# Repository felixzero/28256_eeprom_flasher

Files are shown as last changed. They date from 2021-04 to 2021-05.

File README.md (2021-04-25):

# 28256_eeprom_flasher
Hardware and software for an EEPROM flasher for 28256 EEPROMs.

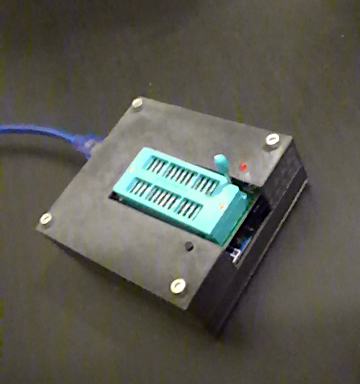
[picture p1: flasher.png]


## How does it work?
- The electronics CAD files are in the `electronics`. You will need Kicad to open them.
- The 3d printed plastic enclosure CAD files are in the `mechanical` folder. You will need FreeCAD.
- The Arduino sketch is in the `firmware` folder.
- The Python script (to communicate with the flasher) is in the `software` folder.

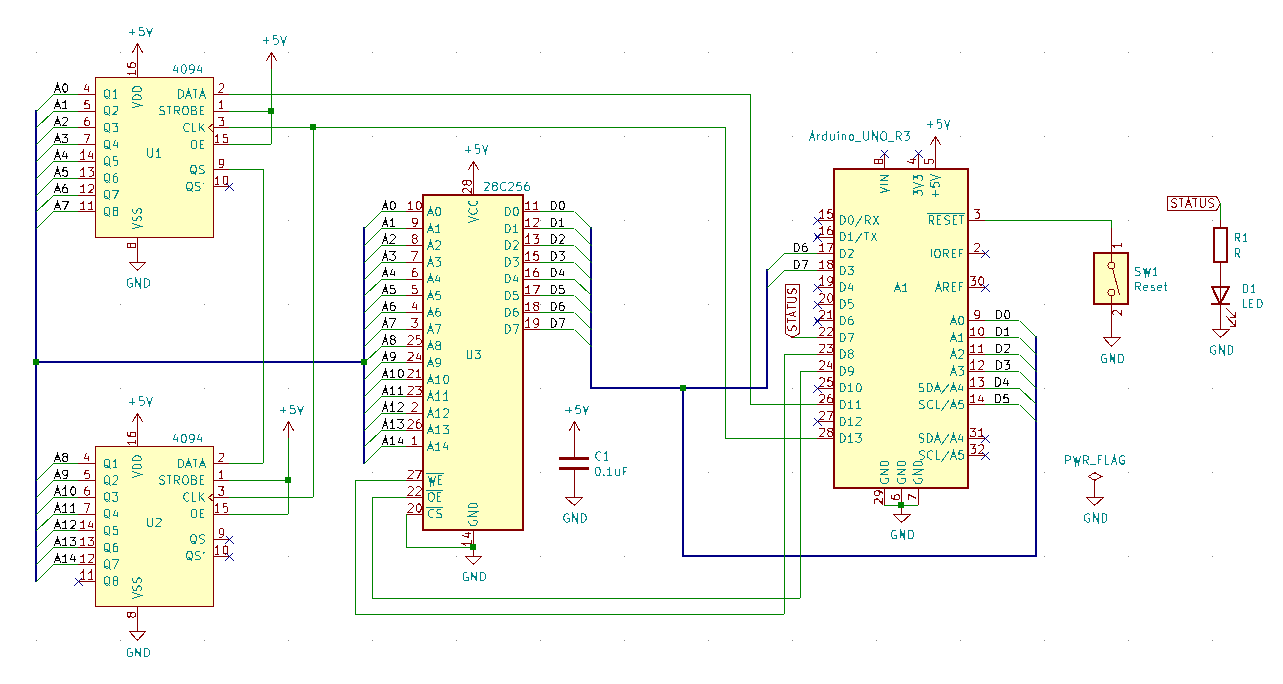
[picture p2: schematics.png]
Electrical schematics


## I just want it
Then you can simply download [the production files](production-files.zip):
- Send the `gerber.zip` file to a PCB manufacturer
- Use a 3d printer to print the two `.obj` files
- Checkout the Git repository to download the software

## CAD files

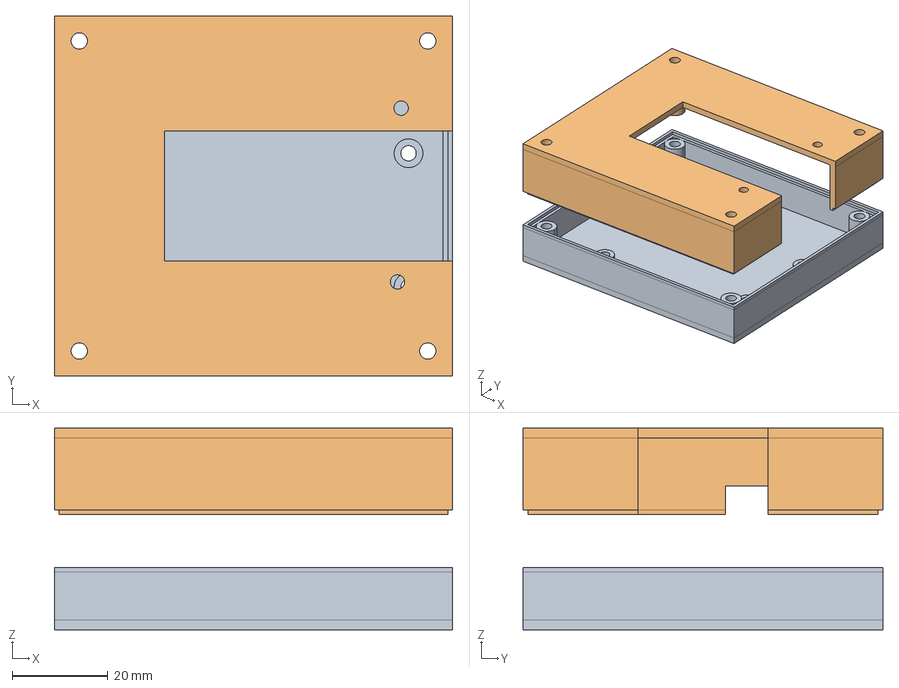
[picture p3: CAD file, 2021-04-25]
mechanical/enclosure.FCStd
83.0 x 75.0 x 42.0 mm
Fond
Dessus

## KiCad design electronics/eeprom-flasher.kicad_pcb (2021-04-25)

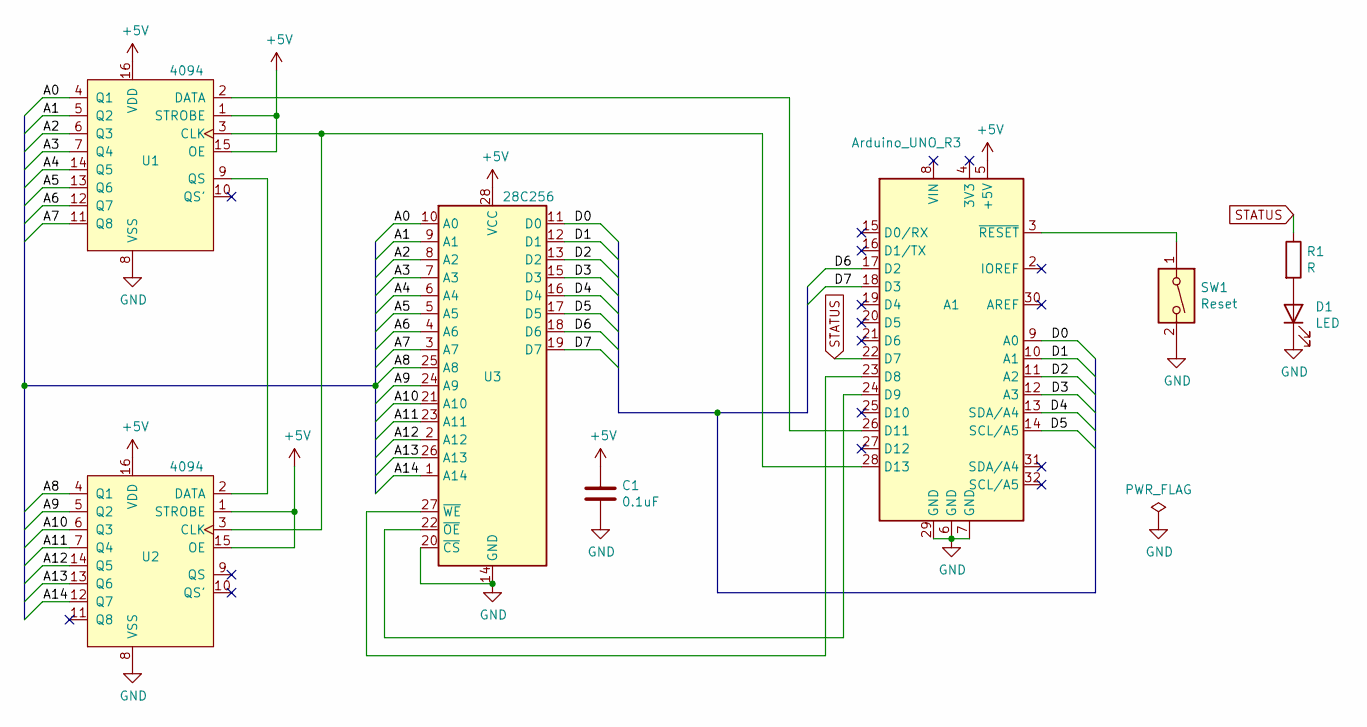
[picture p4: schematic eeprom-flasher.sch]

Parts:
A1: Arduino_UNO_R3
C1: 0.1uF; C_Rect_L7.2mm_W3.0mm_P5.00mm_FKS2_FKP2_MKS2_MKP2
D1: LED; LED_D3.0mm_FlatTop
R1: R; R_Axial_DIN0207_L6.3mm_D2.5mm_P2.54mm_Vertical
SW1: Reset; SW_PUSH_6mm
U1, U2: 4094; DIP-16_W7.62mm_LongPads
U3: 28C256; DIP_Socket-28_W11.9_W12.7_W15.24_W17.78_W18.5_3M_228-1277-0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

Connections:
+5V: A1.5 (+5V), C1.1, U1.1 (STROBE), U1.15 (OE), U1.16 (VDD), U2.1 (STROBE), U2.15 (OE), U2.16 (VDD), U3.28 (VCC)
/A0: U1.4 (Q1), U3.10 (A0)
/A1: U1.5 (Q2), U3.9 (A1)
/A2: U1.6 (Q3), U3.8 (A2)
/A3: U1.7 (Q4), U3.7 (A3)
/A4: U1.14 (Q5), U3.6 (A4)
/A5: U1.13 (Q6), U3.5 (A5)
/A6: U1.12 (Q7), U3.4 (A6)
/A7: U1.11 (Q8), U3.3 (A7)
/A8: U2.4 (Q1), U3.25 (A8)
/A9: U2.5 (Q2), U3.24 (A9)
/A10: U2.6 (Q3), U3.21 (A10)
/A11: U2.7 (Q4), U3.23 (A11)
/A12: U2.14 (Q5), U3.2 (A12)
/A13: U2.13 (Q6), U3.26 (A13)
/A14: U2.12 (Q7), U3.1 (A14)
/D0: A1.9 (A0), U3.11 (D0)
/D1: A1.10 (A1), U3.12 (D1)
/D2: A1.11 (A2), U3.13 (D2)
/D3: A1.12 (A3), U3.15 (D3)
/D4: A1.13 (SDA/A4), U3.16 (D4)
/D5: A1.14 (SCL/A5), U3.17 (D5)
/D6: A1.17 (D2), U3.18 (D6)
/D7: A1.18 (D3), U3.19 (D7)
GND: A1.6 (GND), A1.7 (GND), A1.29 (GND), C1.2, D1.1 (K), SW1.2, U1.8 (VSS), U2.8 (VSS), U3.14 (GND), U3.20 (~CS)
unnamed: A1.3 (~RESET), SW1.1
unnamed: A1.23 (D8), U3.27 (~WE)
unnamed: A1.24 (D9), U3.22 (~OE)
unnamed: A1.26 (D11), U1.2 (DATA)
unnamed: A1.28 (D13), U1.3 (CLK), U2.3 (CLK)
unnamed: D1.2 (A), R1.2
unnamed: U1.9 (QS), U2.2 (DATA)
STATUS: A1.22 (D7), R1.1

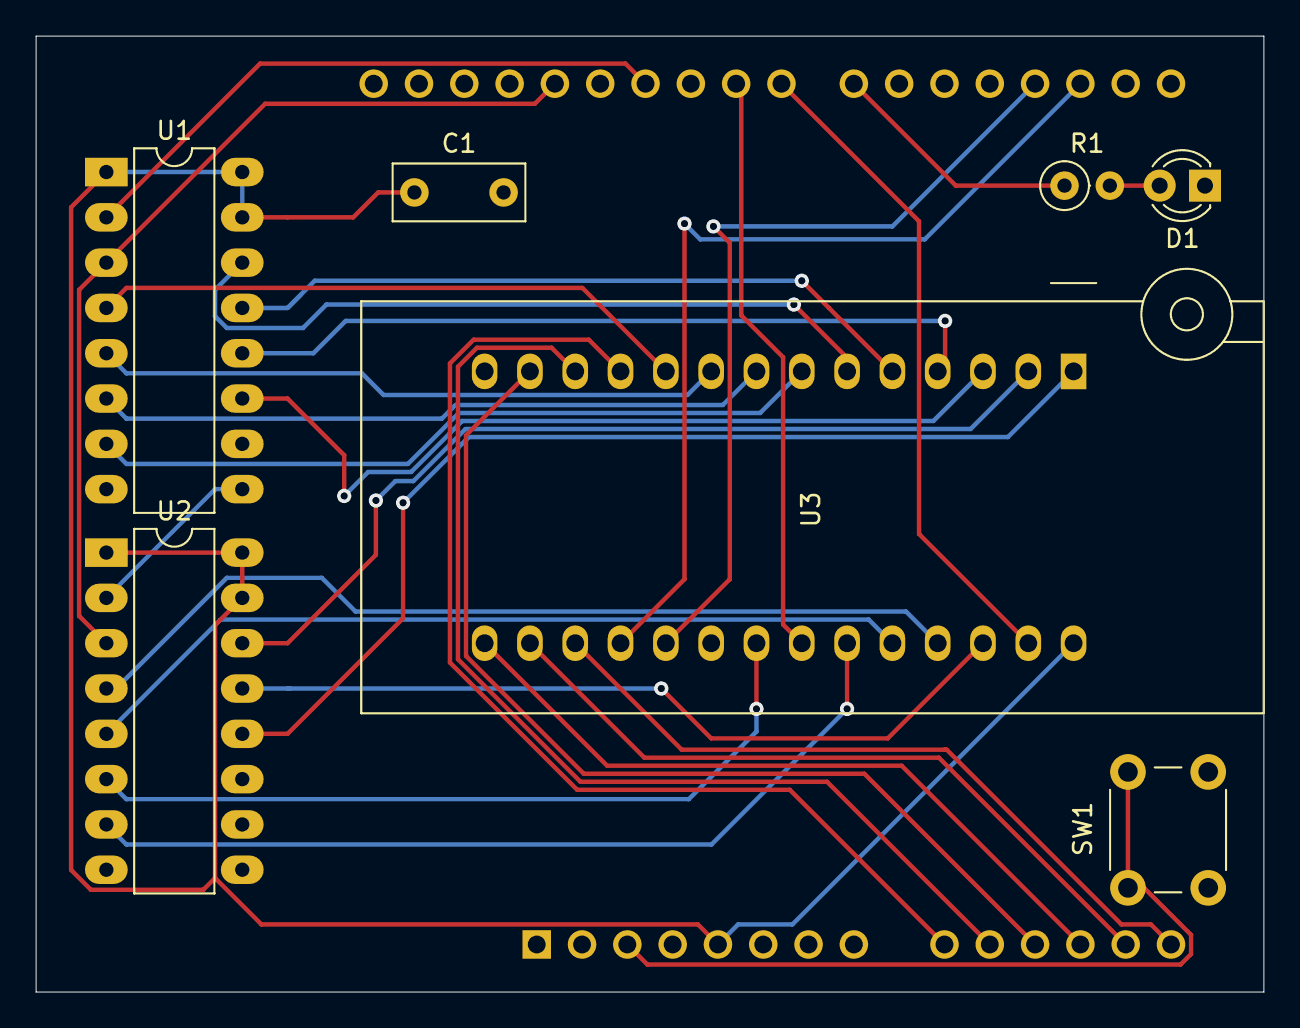
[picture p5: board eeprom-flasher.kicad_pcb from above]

Board: 2 copper layers, 68.8 x 53.6 mm, 8 parts (1 on the bottom side), 33 nets.

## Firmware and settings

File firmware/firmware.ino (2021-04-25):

#define SERIAL_BAUD_RATE 115200

#define PAGE_SIZE 64

#define READ_PAGE_CMD 'r'
#define WRITE_PAGE_CMD 'w'

#define PROCESSED '0'
#define ERROR_INVALID_COMMAND '1'
#define ERROR_BUFFER_TIMEOUT '2'
#define ERROR_ADDR_NOT_AT_BEGINNING_OF_PAGE '3'

#include "eeprom.h"

void setup() {
  Serial.begin(SERIAL_BAUD_RATE);
  Flasher.begin();
}

void loop() {
  if (!Serial.available()) {
    return;
  }

  uint8_t command_byte;
  Serial.readBytes(&command_byte, 1);

  switch(command_byte) {
  case READ_PAGE_CMD:
    handle_read();
    break;

  case WRITE_PAGE_CMD:
    handle_write();
    break;

  default:
    handle_error(ERROR_INVALID_COMMAND);
  }
}

void handle_read() {
  static uint8_t read_buffer[2];
  static uint8_t output_buffer[PAGE_SIZE];
  
  if (Serial.readBytes(read_buffer, 2) != 2) {
    handle_error(ERROR_BUFFER_TIMEOUT);
    return;
  }

  uint16_t eeprom_addr = read_buffer[0] + read_buffer[1] * 256;
  if (eeprom_addr % PAGE_SIZE != 0) {
    handle_error(ERROR_ADDR_NOT_AT_BEGINNING_OF_PAGE);
    return;
  }

  Flasher.read_page(eeprom_addr, output_buffer);
  Serial.write(PROCESSED);
  Serial.write(output_buffer, PAGE_SIZE);
}

void handle_write() {
  static uint8_t read_buffer[PAGE_SIZE + 2];
  
  if (Serial.readBytes(read_buffer, PAGE_SIZE + 2) != (PAGE_SIZE + 2)) {
    handle_error(ERROR_BUFFER_TIMEOUT);
    return;
  }

  uint16_t eeprom_addr = read_buffer[0] + read_buffer[1] * 256;
  if (eeprom_addr % PAGE_SIZE != 0) {
    handle_error(ERROR_ADDR_NOT_AT_BEGINNING_OF_PAGE);
    return;
  }

  Flasher.write_page(eeprom_addr, read_buffer + 2);
  Serial.write(PROCESSED);
}

void handle_error(char error_code) {
  Serial.write(error_code);
}

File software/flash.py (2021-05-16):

#!/usr/bin/python3

import sys
import argparse
import serial
import struct
import time
import hashlib
import os

SERIAL_BAUD_RATE = 115200
SERIAL_TIMEOUT = 2.0
PAGE_SIZE = 64

class SerialHandler:
    def __init__(self, block_device):
        self.serial = serial.Serial(block_device, SERIAL_BAUD_RATE, timeout=SERIAL_TIMEOUT, exclusive=True)

        # Reset the Arduino
        # This is needed because the Arduino resets itself on first serial transfer
        self.serial.write('\x00'.encode('ascii'))
        self.serial.read()

    def read_page(self, address):
        return self._send_command(struct.pack('<cH', 'r'.encode('ascii'), address), PAGE_SIZE)

    def write_page(self, address, data):
        if len(data) != PAGE_SIZE:
            raise ValueError("Page data should have a length of {}".format(PAGE_SIZE))
        self._send_command(struct.pack('<cH{}s'.format(PAGE_SIZE), 'w'.encode('ascii'), address, data), 0)

    def _send_command(self, command, response_size):
        self.serial.write(command)
        response = self.serial.read(1 + response_size)
        if response[0] != ord('0'):
            raise Exception('Flasher responded with code {}'.format(response[0]))
        return response[1:]


if __name__ == "__main__":
    parser = argparse.ArgumentParser(description='Flash a 32K file to an EEPROM')
    parser.add_argument('-i', '--input', required=True)
    parser.add_argument('-o', '--output', required=True)
    namespace = vars(parser.parse_args(sys.argv[1:]))

    input_file = namespace['input']
    output_file = namespace['output']

    if os.path.getsize(input_file) != 32*1024:
        print("Input size must be exactly 32K long")
        exit(1)

    handler = SerialHandler(output_file)
    with open(input_file, 'rb') as f:
        file_content = f.read()
        file_digest = hashlib.md5(file_content)

        print('Input file digest is {}'.format(file_digest.hexdigest()))

        print('Start flashing...')
        for addr in range(0x0000, 0x8000, PAGE_SIZE):
            handler.write_page(addr, file_content[addr:addr+PAGE_SIZE])
            if addr % 0x1000 == 0:
                print('Finished page {:X}'.format(addr))

        print('Flashing done; checking EEPROM digest...')
        mem_digest = hashlib.md5()
        for addr in range(0x0000, 0x8000, PAGE_SIZE):
            mem_digest.update(handler.read_page(addr))
        print('EEPROM digest is {}'.format(mem_digest.hexdigest()))
